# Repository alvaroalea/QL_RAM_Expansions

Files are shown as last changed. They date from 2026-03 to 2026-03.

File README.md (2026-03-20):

# SINCLAIR QL RAM Expansion Boards

(C) 2022-2026 Alvaro Alea Fernandez and others

If no license is specify in each folder, are under: CERN Open Hardware Licence Version 2 - Strongly Reciprocal

https://ohwr.org/cern_ohl_s_v2.txt

This reporsitory contains severals design of RAM expansion boards for the Sinclair QL, some of them area new design, and other are reverse enginiered of products seld in the 80's for the sinclair QL:

## QL_external_ram_896Kb

New design in 2026, based on qubide card of liont, https://hackaday.io/project/183490-qubide-clone-with-640k-or-704k-ram-upgrade-for-ql

Include a 1Mbyte StaticRam in a very small board with pass-through. This is the prefered design if you are new to the Sinclair QL

## qlexternal512kram_MIX

My old 2022 design, based on qubide card of Jose Leandro and work of McLeod Ideafix, using a 512Kb StaticRam in a very small board with pass-through. two of this board can be stacked to achive the 892Kb of RAM that is the maximun possible on a Sinclair QL

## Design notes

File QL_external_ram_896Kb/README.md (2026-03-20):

# SINCLAIR QL 896kB External Rom Expansion

(C) 2026 Alvaro Alea Fernandez

License under: CERN Open Hardware Licence Version 2 - Strongly Reciprocal

https://ohwr.org/cern_ohl_s_v2.txt

This is based on the work of McLeod Ideafix, Jose Leandro, Zerover and tcat between others. 

This board will provide up to 768kB aditional of static RAM (fast-ram) to the sinclair QL.

This board can be stacked with my old external ram board, jumpers allow a 512Kb, or +256Kb configs of the old board.

There is also a expecial 832Kb config that free the 64Kb top memory for aditional boards without use the ROM Cartridge area (Jose Leandro's QuBide...)

Provide a expansion conector to allow conect aditional interfaces.

There area available 4 configuration trough a dip switch in the PCB.
* 640kB - This is the standar 512kB expansion for any QL
* 832kB - Similar to 256kB provide aditional space for expansion cards correctly configured.
* 896kB - Maximin RAM do not provide aditional space for expansion cards.
* Expecial - This is for use as a second expansion, use the full QL space for a maximun of 898kB, be aware that this is incompatible with a lot of expansion card, so use with caution (Any expansion card that do not use jumper for configuration will be incompatible).

In the GAL folder there is the source code to be compiled with GALasm that you can found here: https://github.com/daveho/GALasm

## Mini Trump Card Compatibility

I have done a version of the trump card disk interface here: https://github.com/alvaroalea/QL_MiniTrump3 , this interface do not
provide memory like the original one. You can combine both cards to mimic the original trump card.

You shall connect this board after the minitrump, you need to change the solder jumper (JP1) to 1-2 to allow the Minitrump card to coordinate with the second memory card.

This jumper can be alwais 1-2, 2-3 is only used if you have another card that need BERR signal (none as far as I know).

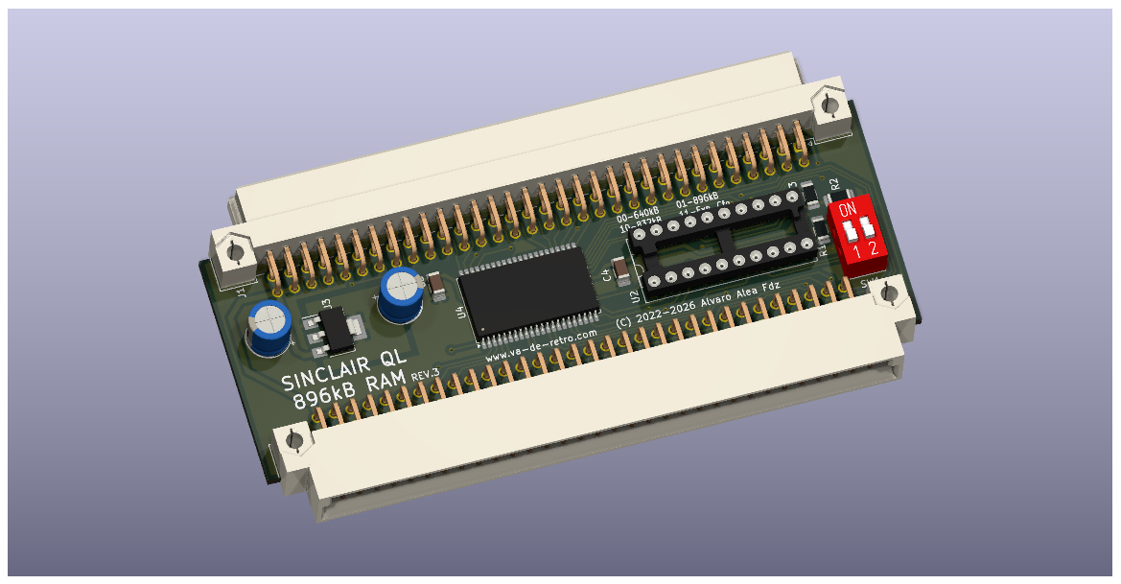
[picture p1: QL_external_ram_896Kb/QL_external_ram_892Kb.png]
My image


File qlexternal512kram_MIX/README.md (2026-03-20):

# SINCLAIR QL 512kB External Rom Expansion

(C) 2022 Alvaro Alea Fernandez

License under: CERN Open Hardware Licence Version 2 - Strongly Reciprocal

https://ohwr.org/cern_ohl_s_v2.txt

This is based on the work of McLeod Ideafix, Jose Leandro, Zerover and tcat between others. 

This board will provide up to 512kB aditional of static RAM (fast-ram) to the sinclair QL.

Two board can be stacked to got a maximun of 898Kb of Memory. (same as Miracle's Trump Card)

Be aware you can not have 2 memory expansion in same area (Jose Leandro's QBide, Trump Card, etc...)

Provide a expansion conector to allow conect aditional interfaces.

There area available 4 configuration trough solder jumpers in the PCB.
* 512kB - This is the standar 512kB expansion for any QL
* 256kB - This is for use as a second expansion, use the full QL space for a maximun of 898kB, be aware that this is incompatible with a lot of expansion card, so use with caution (Any expansion card that do not use jumper for configuration will be incompatible).
* 192kB - Similar to 256kB provide aditional space for expansion cards correctly configured.
* 128kB - Similar to 256kB provide aditional space for expansion cards correctly configured.

Be aware that the configuration of 128Kb can not be installed alone.
For be able to use 128kB, for a total of 768kB, is mandatory to have an aditional expansion card that put ROM in address E00000h, in other case the QL ROM will hang indicating RAM malfunction, because a weired overlap of the internal 128kB with this external 128kB.

https://www.instagram.com/p/CZWfWcUM5mx/

In the GAL folder there is the source code to be compiled with GALasm that you can found here: https://github.com/daveho/GALasm

## Mini Trump Card Compatibility

I have done a version of the trump card disk interface here: https://github.com/alvaroalea/QL_MiniTrump3 , this interface do not
provide memory like the original one. You can combine two of this card and the minitrump to got the same of the original trump card.

You should conect the 512Kb Card to the QL, the MiniTrump Card to the 512Kb, and the +256Kb card to the Mini Trump, and in this board
yo need to change the solder jumper (JP1) to 2-3 to allow the Minitrump card to coordinate with the second memory card.

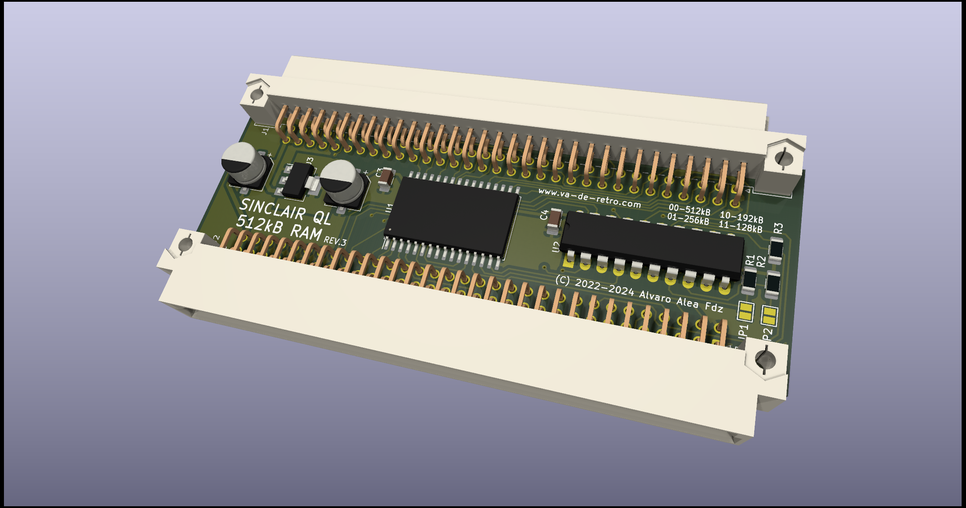
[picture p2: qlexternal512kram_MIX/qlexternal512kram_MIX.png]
My image


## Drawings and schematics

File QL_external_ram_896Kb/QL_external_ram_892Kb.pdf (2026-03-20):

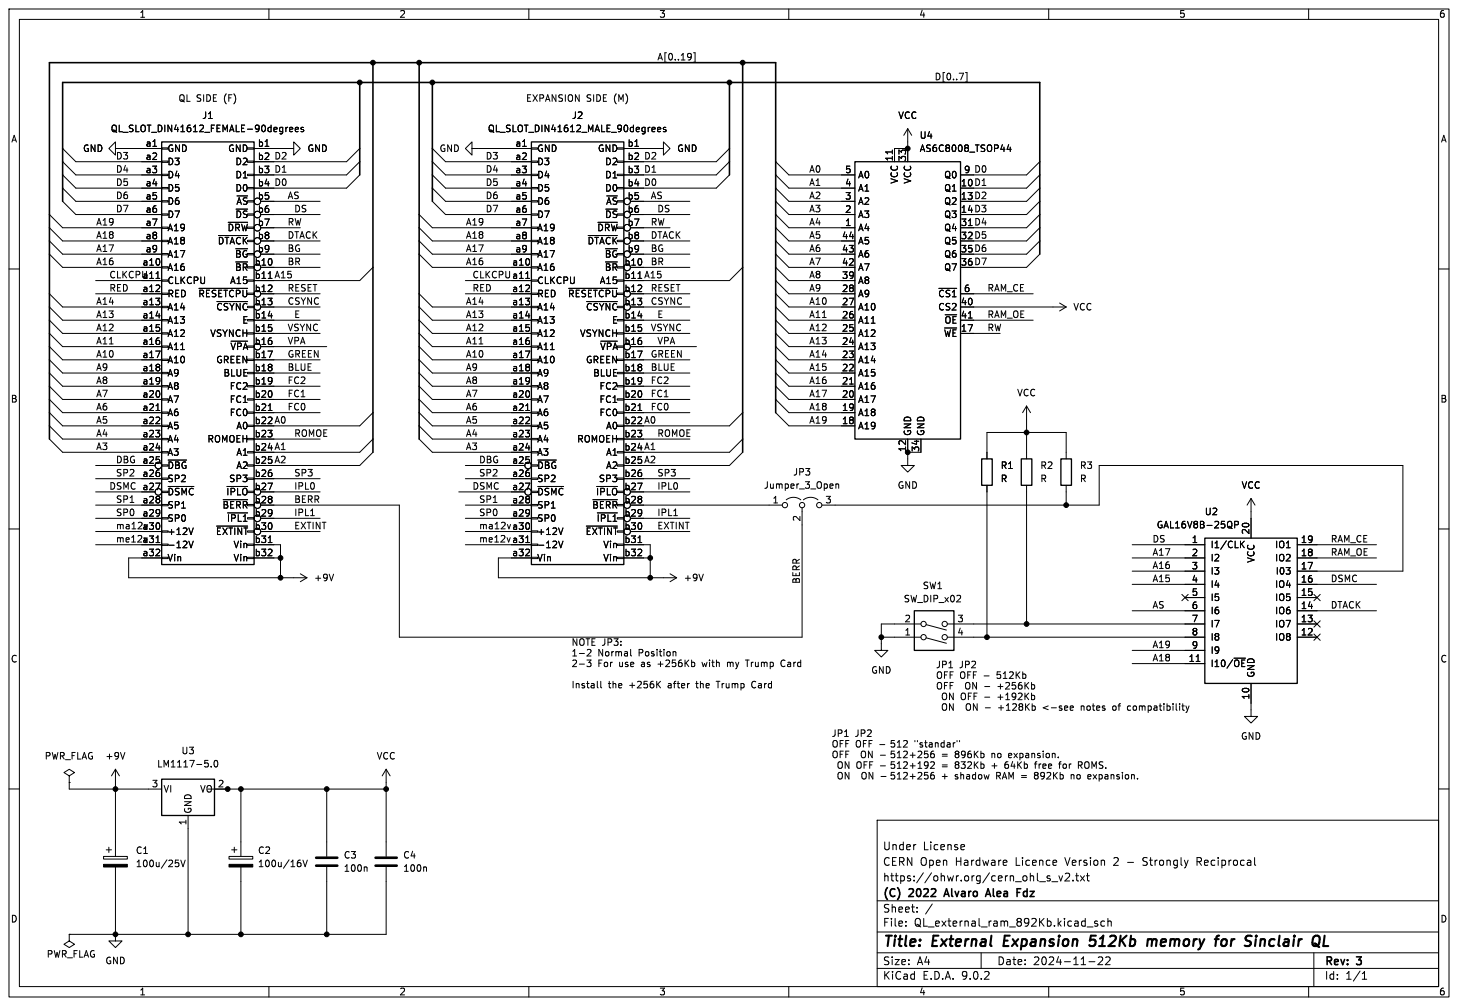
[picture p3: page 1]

EXPANSION SIDE (M) J1 QL_SLOT_DIN41612_FEMALE-90degrees GND a1 D3 a2 D4 a3 D5 a4 D6 a5 D7 a6 A19 a7 A18 a8 A17 a9 A16 a10 CLKCPU a11 RED a12 A14 a13 A13 a14 A12 a15 A11 a16 A10 a17 A9 a18 A8 a19 A7 a20 A6 a21 A5 a22 A4 a23 A3 a24 ~{DBG} a25 SP2 a26 ~{DSMC} a27 SP1 a28 SP0 a29 +12V a30

3 SW1 SW_DIP_x02 GND a1 D3 a2 D4 a3 D5 a4 D6 a5 D7 a6 A19 a7 A18 a8 A17 a9 A16 a10 CLKCPU a11 RED a12 A14 a13 A13 a14 A12 a15 A11 a16 A10 a17 A9 a18 A8 a19 A7 a20 A6 a21 A5 a22 A4 a23 A3 a24 ~{DBG} a25 SP2 a26 ~{DSMC} a27 SP1 a28 SP0 a29 +12V a30

b14 VSYNCH b15 ~{VPA}b16 GREEN b17 BLUE b18 FC2 b19 FC1 b20 FC0 b21 A0 b22 ROMOEH b23 A1 b24 A2 b25 SP3 b26 ~{IPLO}b27 ~{BERR}b28 ~{IPL1}b29 ~{EXTINT}b30 Vin b31 Vin b32

Id: 1/1 Title: External Expansion 512Kb memory for Sinclair QL

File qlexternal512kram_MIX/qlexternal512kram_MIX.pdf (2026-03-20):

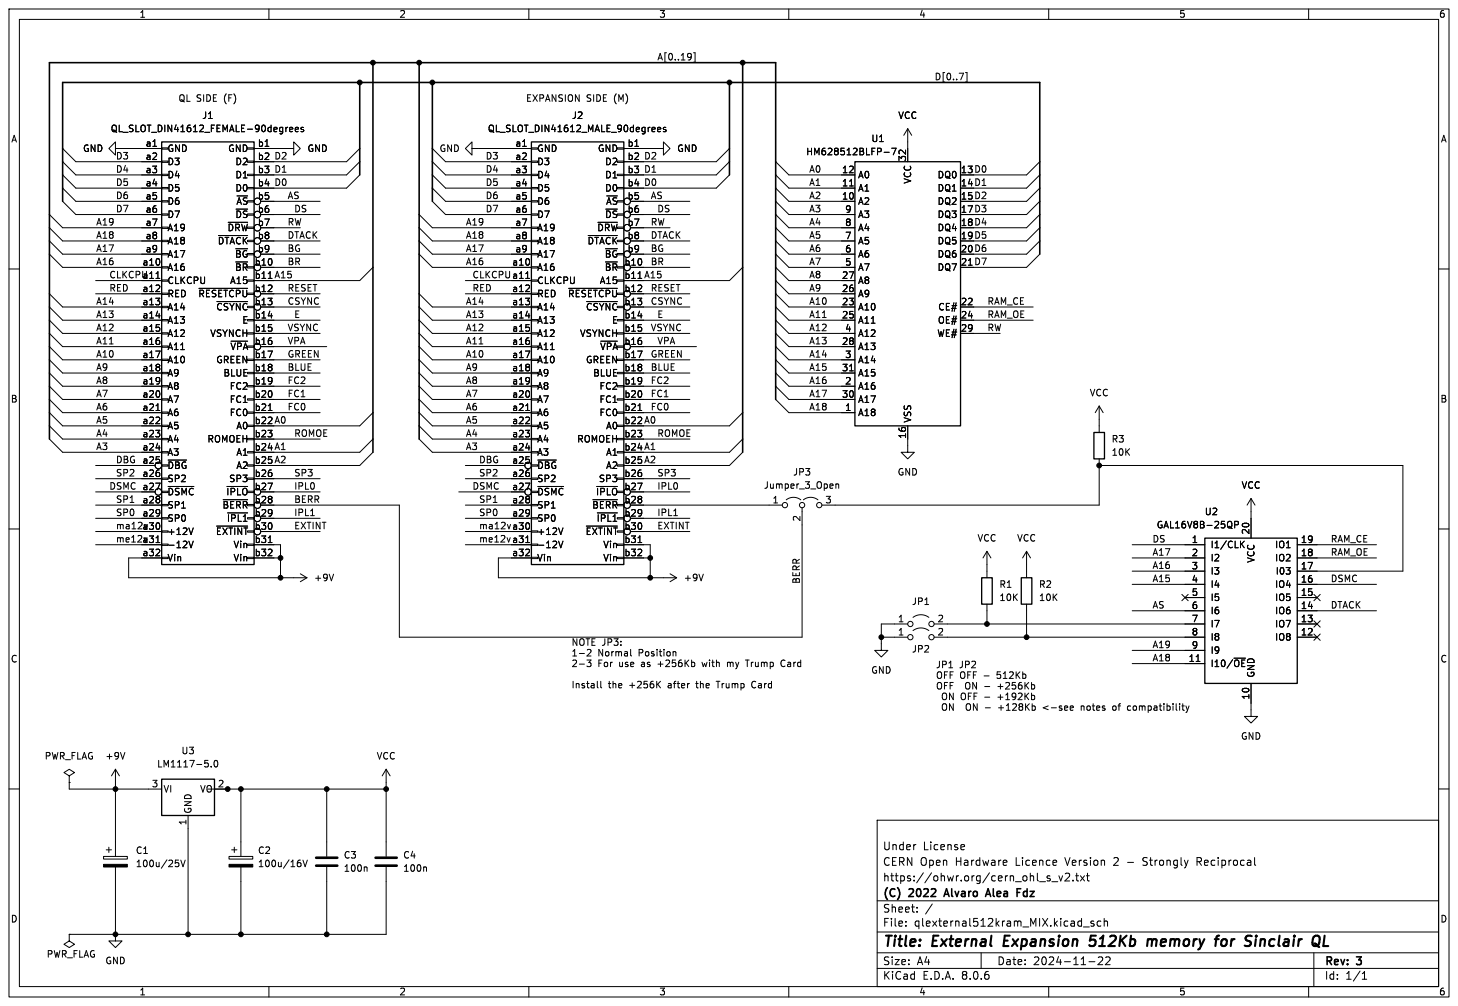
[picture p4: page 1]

J1 QL_SLOT_DIN41612_FEMALE-90degrees GND a1 A16 a10 CLKCPU a11 RED a12 A14 a13 A13 a14 A12 a15 A11 a16 A10 a17 A9 a18 A8 a19 D3 a2 A7 a20 A6 a21 A5 a22 A4 a23 A3 a24 ~{DBG} a25 SP2 a26 ~{DSMC} a27 SP1 a28 SP0 a29 D4 a3 +12V a30
b14 VSYNCH b15 ~{VPA}b16 GREEN b17 BLUE b18 FC2 b19 D2 b2 FC1 b20 FC0 b21 A0 b22 ROMOEH b23 A1 b24 A2 b25 SP3 b26 ~{IPLO}b27 ~{BERR}b28 ~{IPL1}b29 D1 b3 ~{EXTINT}b30 Vin b31 Vin b32 D0 b4 ~{AS}b5 ~{DS}b6 ~{DRW}b7 ~{DTACK}b8 ~{BG}b9
ASCSYNC

VCC GND a1 A16 a10 CLKCPU a11 RED a12 A14 a13 A13 a14 A12 a15 A11 a16 A10 a17 A9 a18 A8 a19 D3 a2 A7 a20 A6 a21 A5 a22 A4 a23 A3 a24 ~{DBG} a25 SP2 a26 ~{DSMC} a27 SP1 a28 SP0 a29 D4 a3 +12V a30

Id: 1/1 Title: External Expansion 512Kb memory for Sinclair QL

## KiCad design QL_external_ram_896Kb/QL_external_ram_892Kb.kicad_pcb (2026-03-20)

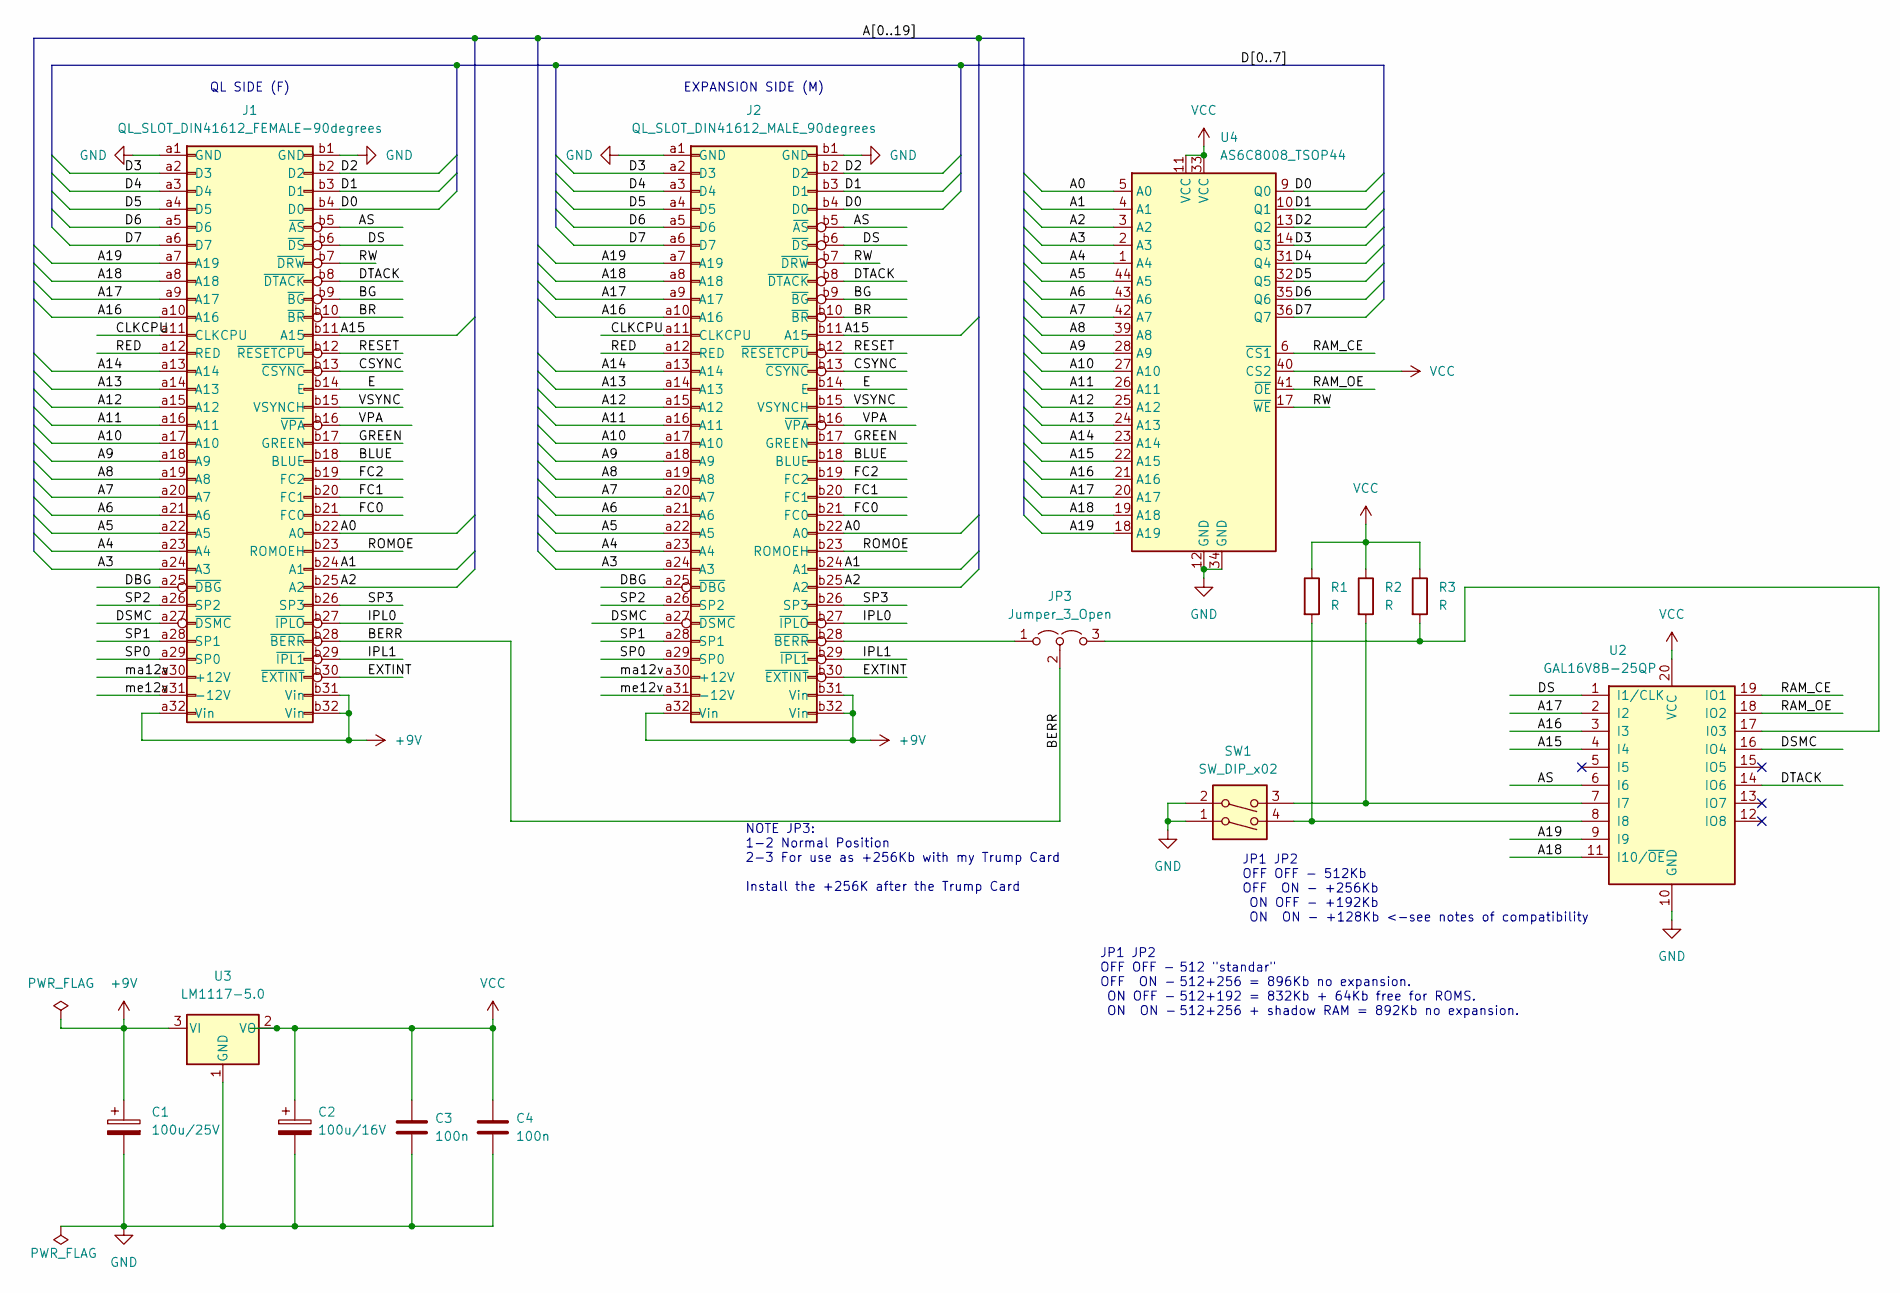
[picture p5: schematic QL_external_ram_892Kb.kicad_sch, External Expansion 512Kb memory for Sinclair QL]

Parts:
C1: 100u/25V; CP_Radial_D6.3mm_P2.50mm
C2: 100u/16V; CP_Radial_D6.3mm_P2.50mm
C3, C4: 100n; C_1206_3216Metric_Pad1.33x1.80mm_HandSolder
J1: QL_SLOT_DIN41612_FEMALE-90degrees; DIN41612_B_2x32_Female_Horizontal_THT
J2: QL_SLOT_DIN41612_MALE_90degrees; DIN41612_B_2x32_Male_Horizontal_THT
JP3: Jumper_3_Open; SolderJumper-3_P1.3mm_Open_Pad1.0x1.5mm
R1, R2, R3: R; R_1206_3216Metric_Pad1.30x1.75mm_HandSolder
SW1: SW_DIP_x02; DIP-4_W7.62mm_Socket
U2: GAL16V8B-25QP; DIP-20_W7.62mm_Socket
U3: LM1117-5.0; SOT-223-3_TabPin2
U4: AS6C8008_TSOP44; TSOP-II-44_10.16x18.41mm_P0.8mm

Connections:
+9V: C1.1, J1.a32 (Vin), J1.b31 (Vin), J1.b32 (Vin), J2.a32 (Vin), J2.b31 (Vin), J2.b32 (Vin), U3.3 (VI)
/A0: J1.b22 (A0), J2.b22 (A0), U4.5 (A0)
/A1: J1.b24 (A1), J2.b24 (A1), U4.4 (A1)
/A2: J1.b25 (A2), J2.b25 (A2), U4.3 (A2)
/A3: J1.a24 (A3), J2.a24 (A3), U4.2 (A3)
/A4: J1.a23 (A4), J2.a23 (A4), U4.1 (A4)
/A5: J1.a22 (A5), J2.a22 (A5), U4.44 (A5)
/A6: J1.a21 (A6), J2.a21 (A6), U4.43 (A6)
/A7: J1.a20 (A7), J2.a20 (A7), U4.42 (A7)
/A8: J1.a19 (A8), J2.a19 (A8), U4.39 (A8)
/A9: J1.a18 (A9), J2.a18 (A9), U4.28 (A9)
/A10: J1.a17 (A10), J2.a17 (A10), U4.27 (A10)
/A11: J1.a16 (A11), J2.a16 (A11), U4.26 (A11)
/A12: J1.a15 (A12), J2.a15 (A12), U4.25 (A12)
/A13: J1.a14 (A13), J2.a14 (A13), U4.24 (A13)
/A14: J1.a13 (A14), J2.a13 (A14), U4.23 (A14)
/A15: J1.b11 (A15), J2.b11 (A15), U2.4 (I4), U4.22 (A15)
/A16: J1.a10 (A16), J2.a10 (A16), U2.3 (I3), U4.21 (A16)
/A17: J1.a9 (A17), J2.a9 (A17), U2.2 (I2), U4.20 (A17)
/A18: J1.a8 (A18), J2.a8 (A18), U2.11 (I10/~OE), U4.19 (A18)
/A19: J1.a7 (A19), J2.a7 (A19), U2.9 (I9), U4.18 (A19)
/AS: J1.b5 (~AS), J2.b5 (~AS), U2.6 (I6)
/BERR: J1.b28 (~BERR), JP3.2 (C)
/BG: J1.b9 (~BG), J2.b9 (~BG)
/BLUE: J1.b18 (BLUE), J2.b18 (BLUE)
/BR: J1.b10 (~BR), J2.b10 (~BR)
/CLKCPU: J1.a11 (CLKCPU), J2.a11 (CLKCPU)
/CSYNC: J1.b13 (~CSYNC), J2.b13 (~CSYNC)
/D0: J1.b4 (D0), J2.b4 (D0), U4.9 (Q0)
/D1: J1.b3 (D1), J2.b3 (D1), U4.10 (Q1)
/D2: J1.b2 (D2), J2.b2 (D2), U4.13 (Q2)
/D3: J1.a2 (D3), J2.a2 (D3), U4.14 (Q3)
/D4: J1.a3 (D4), J2.a3 (D4), U4.31 (Q4)
/D5: J1.a4 (D5), J2.a4 (D5), U4.32 (Q5)
/D6: J1.a5 (D6), J2.a5 (D6), U4.35 (Q6)
/D7: J1.a6 (D7), J2.a6 (D7), U4.36 (Q7)
/DBG: J1.a25 (~DBG), J2.a25 (~DBG)
/DS: J1.b6 (~DS), J2.b6 (~DS), U2.1 (I1/CLK)
/DSMC: J1.a27 (~DSMC), J2.a27 (~DSMC), U2.16 (IO4)
/DTACK: J1.b8 (~DTACK), J2.b8 (~DTACK), U2.14 (IO6)
/E: J1.b14 (E), J2.b14 (E)
/EXTINT: J1.b30 (~EXTINT), J2.b30 (~EXTINT)
/FC0: J1.b21 (FC0), J2.b21 (FC0)
/FC1: J1.b20 (FC1), J2.b20 (FC1)
/FC2: J1.b19 (FC2), J2.b19 (FC2)
/GREEN: J1.b17 (GREEN), J2.b17 (GREEN)
/IPL0: J1.b27 (~IPLO), J2.b27 (~IPLO)
/IPL1: J1.b29 (~IPL1), J2.b29 (~IPL1)
/RAM_CE: U2.19 (IO1), U4.6 (~CS1)
/RAM_OE: U2.18 (IO2), U4.41 (~OE)
/RED: J1.a12 (RED), J2.a12 (RED)
/RESET: J1.b12 (~RESETCPU), J2.b12 (~RESETCPU)
/ROMOE: J1.b23 (ROMOEH), J2.b23 (ROMOEH)
/RW: J1.b7 (~DRW), J2.b7 (~DRW), U4.17 (~WE)
/SP0: J1.a29 (SP0), J2.a29 (SP0)
/SP1: J1.a28 (SP1), J2.a28 (SP1)
/SP2: J1.a26 (SP2), J2.a26 (SP2)
/SP3: J1.b26 (SP3), J2.b26 (SP3)
/VPA: J1.b16 (~VPA), J2.b16 (~VPA)
/VSYNC: J1.b15 (VSYNCH), J2.b15 (VSYNCH)
/ma12v: J1.a30 (+12V), J2.a30 (+12V)
/me12v: J1.a31 (-12V), J2.a31 (-12V)
GND: C1.2, C2.2, C3.2, C4.2, J1.a1 (GND), J1.b1 (GND), J2.a1 (GND), J2.b1 (GND), SW1.1, SW1.2, U2.10 (GND), U3.1 (GND), U4.12 (GND), U4.34 (GND)
unnamed: J2.b28 (~BERR), JP3.1 (A)
unnamed: JP3.3 (B), R3.2, U2.17 (I03)
unnamed: R2.2, SW1.3, U2.7 (I7)
unnamed: R1.2, SW1.4, U2.8 (I8)
VCC: C2.1, C3.1, C4.1, R1.1, R2.1, R3.1, U2.20 (VCC), U3.2 (VO), U4.11 (VCC), U4.33 (VCC), U4.40 (CS2)

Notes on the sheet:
NOTE JP3: 1-2 Normal Position 2-3 For use as +256Kb with my Trump Card Install the +256K after the Trump Card
512 "standar" 512+256 = 896Kb no expansion. 512+192 = 832Kb + 64Kb free for ROMS. 512+256 + shadow RAM = 892Kb no expansion.
EXPANSION SIDE (M)
JP1 JP2 OFF OFF - 512Kb OFF ON - +256Kb ON OFF - +192Kb ON ON - +128Kb <-see notes of compatibility
QL SIDE (F)
JP1 JP2 OFF OFF - OFF ON - ON OFF - ON ON -

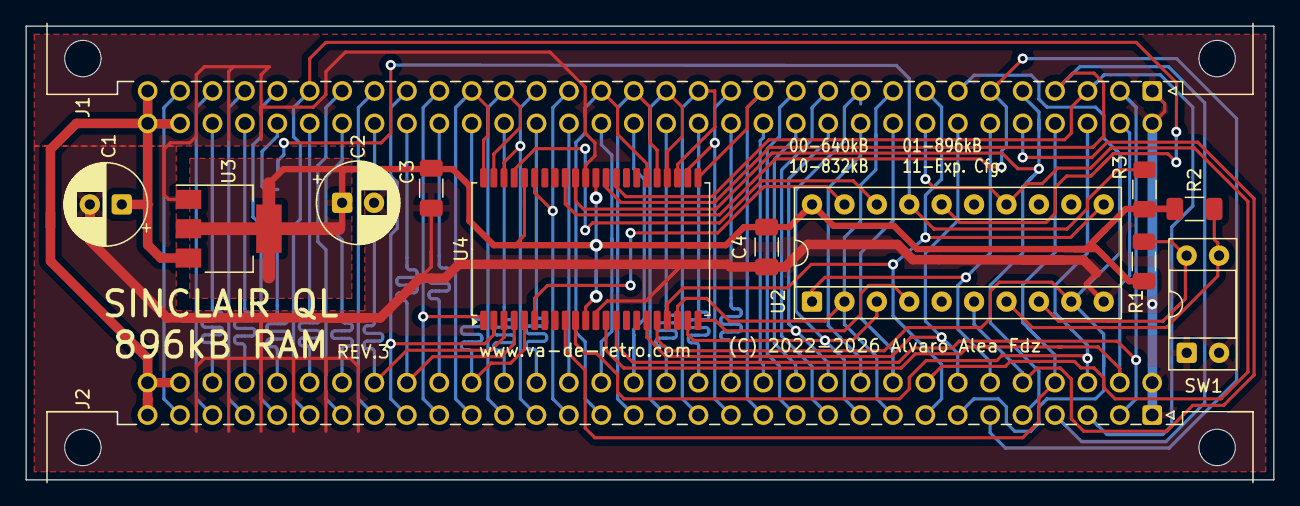
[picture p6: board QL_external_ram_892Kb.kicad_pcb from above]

Board: 2 copper layers, 97.8 x 35.6 mm, 14 parts (1 on the bottom side), 68 nets.

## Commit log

2026-03-20 new boards, and reorganization
    [QL_external_ram_892Kb.kicad_pcb, QL_external_ram_892Kb.kicad_sch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]
2026-03-20 cosmetic changes
    [QL_external_ram_892Kb.kicad_pcb]
2026-03-20 896 :-D
    [QL_external_ram_892Kb.kicad_pcb, QL_external_ram_892Kb.kicad_sch]

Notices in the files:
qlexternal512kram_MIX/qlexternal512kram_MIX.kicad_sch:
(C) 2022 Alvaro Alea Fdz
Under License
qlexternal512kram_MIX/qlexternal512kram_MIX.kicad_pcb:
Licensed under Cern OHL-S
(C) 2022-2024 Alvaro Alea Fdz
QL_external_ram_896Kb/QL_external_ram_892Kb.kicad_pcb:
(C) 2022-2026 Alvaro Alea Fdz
